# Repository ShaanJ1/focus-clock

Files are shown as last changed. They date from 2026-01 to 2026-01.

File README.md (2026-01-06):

# Focus Clock
A small battery powered pomorodo clock that can help you manage your time better. Includes pomorodo timer, custom timer support, screen time reminders, and more!

### Showcase
*Coming soon...*
### Bill of Materials (BOM)

| **Item Name** | **URL** | **Price** | **Quantity** |
|--- |---|---|---|
| SSD1306 OLED Display | [AliExpress](https://www.aliexpress.com/item/1005008640132638.html) | $5.58 | 1 |
| Rotary Encoder | [AliExpress](https://www.aliexpress.com/item/1005009532009840.html) | $14.23 | 1 |
| Vibration Motor | [DigiKey](https://www.digikey.ca/en/products/detail/adafruit-industries-llc/1201/5353637) | $2.82 | 1 |
| Speaker Driver | [DigiKey](https://www.digikey.ca/en/products/detail/dfrobot/DFR0299/6588463) | $8.53 | 1 | 
| Speaker | [DigiKey](https://www.digikey.ca/en/products/detail/soberton-inc/SP-1605-5/8600809) | $3.36 | 1 |
| 3.7V Battery (self provided, not included in total) | - | $0.00 | 1 |
| Adafruit Battery Charger (self provided, not included in total) | - | $0.00 | 1 |
| 1x2 Male Pin Connector | [DigiKey](https://www.digikey.ca/en/products/detail/w-rth-elektronik/61300211121/4846823) | $1.48 | 10 |
| 1x3 Male Pin Connector | [DigiKey](https://www.digikey.ca/en/products/detail/adam-tech/PH1-03-UA/9830289) | $0.15 | 1 |
| 1x4 Male Pin Connector | [DigiKey](https://www.digikey.ca/en/products/detail/adam-tech/PH1-04-UA/9829296) | $0.15 | 1 |
| 1x5 Male Pin Connector | [DigiKey](https://www.digikey.ca/en/products/detail/adam-tech/PH1-05-UA/9830343) | $0.15 | 1 |
| 2x3 Male Pin Connector | [DigiKey](https://www.digikey.ca/en/products/detail/adam-tech/PH2-06-UA/9830396) | $0.18 | 1 |
| PushButton | [DigiKey](https://www.digikey.ca/en/products/detail/same-sky-formerly-cui-devices-/TS02-66-43-BK-100-LCR-D/15634359)  | $0.45 | 3 |
| PCBA | [JLCPCB](https://jlcpcb.com/) | $35.78 | 1 |

**Total (CAD):** $72.86

**Total (USD):** $52.92

### Images
Schematic


PCB



Assembly


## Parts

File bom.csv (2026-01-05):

Bill of Materials
Item Name: | URL: | Price: | Quantity: | Use:
OLED Display | https://www.aliexpress.com/item/1005008640132638.html | $5.58 | 1 | Display
Rotary Encoder | https://www.aliexpress.com/item/1005003824684681.html | $5.50 | 1 | User Input
Vibration Motor | https://www.digikey.ca/en/products/detail/adafruit-industries-llc/1201/5353637 | $2.82 | 1 | Haptic Feedback
Speaker Driver | https://www.digikey.ca/en/products/detail/dfrobot/DFR0299/6588463 | $8.53 | 1 | Audio Driver
Speaker | https://www.digikey.ca/en/products/detail/soberton-inc/SP-1605-5/8600809 | $3.36 | 1 | Audio Output
3.7V Battery (Self Provided) |  | $0.00 | 1 | Power Source
Adafruit Battery Charger (Self Provided) |  | $0.00 | 1 | Battery Charging
1x2 Male Pin Connector | https://www.digikey.ca/en/products/detail/w-rth-elektronik/61300211121/4846823 | $1.48 | 10 | Board Connections
1x3 Male Pin Connector | https://www.digikey.ca/en/products/detail/adam-tech/PH1-03-UA/9830289 | $0.15 | 1 | Board Connections
1x4 Male Pin Connector | https://www.digikey.ca/en/products/detail/adam-tech/PH1-04-UA/9829296 | $0.15 | 1 | Board Connections
1x5 Male Pin Connector | https://www.digikey.ca/en/products/detail/adam-tech/PH1-05-UA/9830343 | $0.15 | 1 | Board Connections
2x3 Male Pin Connector | https://www.digikey.ca/en/products/detail/adam-tech/PH2-06-UA/9830396 | $0.18 | 1 | Board Connections
PushButton | https://www.digikey.ca/en/products/detail/same-sky-formerly-cui-devices-/TS02-66-43-BK-100-LCR-D/15634359 | $0.45 | 3 | User Input Buttons
PCBA | https://jlcpcb.com/ | $35.78 | 1 | Assembled PCB
3D Printing Shipping |  | $10.00 | 1 | 3D Print Shipping Costs
DigiKey Shipping + GST |  | $9.57 | 1 | DigiKey Shipping and tax
 | Total (CAD): | $73.70
 | Total (USD): | $53.57

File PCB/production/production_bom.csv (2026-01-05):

Designator | Footprint | Quantity | Value | LCSC Part #
C1, C2 | 0603 | 2 | 10uF
C10, C11, C12, C13, C14, C15, C17, C20, C24, C8, C9 | 0402 | 11 | 0.1uF
C16, C3 | 0402 | 2 | 1uF
C18, C19 | 0402 | 2 | 33pF
D2 | 0402 | 1 | ONBOARD_LED
D5 | D_DO-35_SOD27_P7.62mm_Horizontal | 1 | 1N4148
D6 | D_DO-41_SOD81_P10.16mm_Horizontal | 1 | 1N5817
J1 | PinHeader_1x02_P2.54mm_Vertical | 1 | Battery_Output
J10, J14, J9 | PinHeader_1x02_P2.54mm_Vertical | 3 | PushButton
J11 | PinHeader_1x02_P2.54mm_Vertical | 1 | LED_RED
J12 | PinHeader_1x02_P2.54mm_Vertical | 1 | LED_GREEN
J13 | PinHeader_1x02_P2.54mm_Vertical | 1 | LED_BLUE
J2 | PinHeader_1x04_P2.54mm_Vertical | 1 | SSD1306
J3 | PinHeader_1x02_P2.54mm_Vertical | 1 | Vibration_Motor
J4 | USB_C_Receptacle_HRO_TYPE-C-31-M-12 | 1 | USB_C_Receptacle_USB2.0_14P
J5 | PinHeader_2x03_P2.54mm_Vertical | 1 | DF Player Mini
J6 | PinHeader_1x03_P2.54mm_Vertical | 1 | Conn_01x03
J7 | PinHeader_1x02_P2.54mm_Vertical | 1 | Battery_Charger
J8 | PinHeader_1x05_P2.54mm_Vertical | 1 | RotaryEncoder
Q1 | SOT-23 | 1 | AO3401A
Q3 | SOT-23 | 1 | Q_NMOS_GSD
R1 | 0402 | 1 | 100
R10 | 0402 | 1 | 100K
R11, R12, R13, R2 | 0402 | 4 | 220
R21, R22 | 0402 | 2 | 4.7K
R3, R4 | 0402 | 2 | 27
R5, R7 | 0402 | 2 | 1K
R6 | 0402 | 1 | 10K
R8, R9 | 0402 | 2 | 5.1K
SW1 | SW_Push_SPST_NO_Alps_SKRK | 1 | SW_Push
U1 | SOT-23 | 1 | MCP1700x-330xxTT
U2 | SOIC-8_5.3x5.3mm_P1.27mm | 1 | W25Q128JVS
U3 | QFN-56-1EP_7x7mm_P0.4mm_EP3.2x3.2mm | 1 | RP2040
Y1 | Crystal_SMD_3225-4Pin_3.2x2.5mm | 1 | 12 MHz

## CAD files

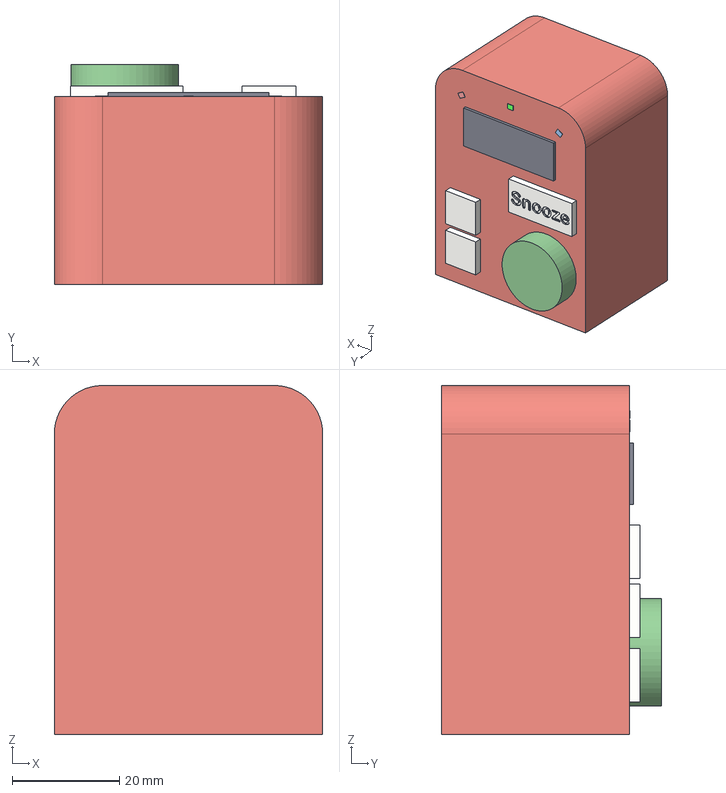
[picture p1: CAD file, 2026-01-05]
CAD/focus_clock.step
50.0 x 41.0 x 65.0 mm

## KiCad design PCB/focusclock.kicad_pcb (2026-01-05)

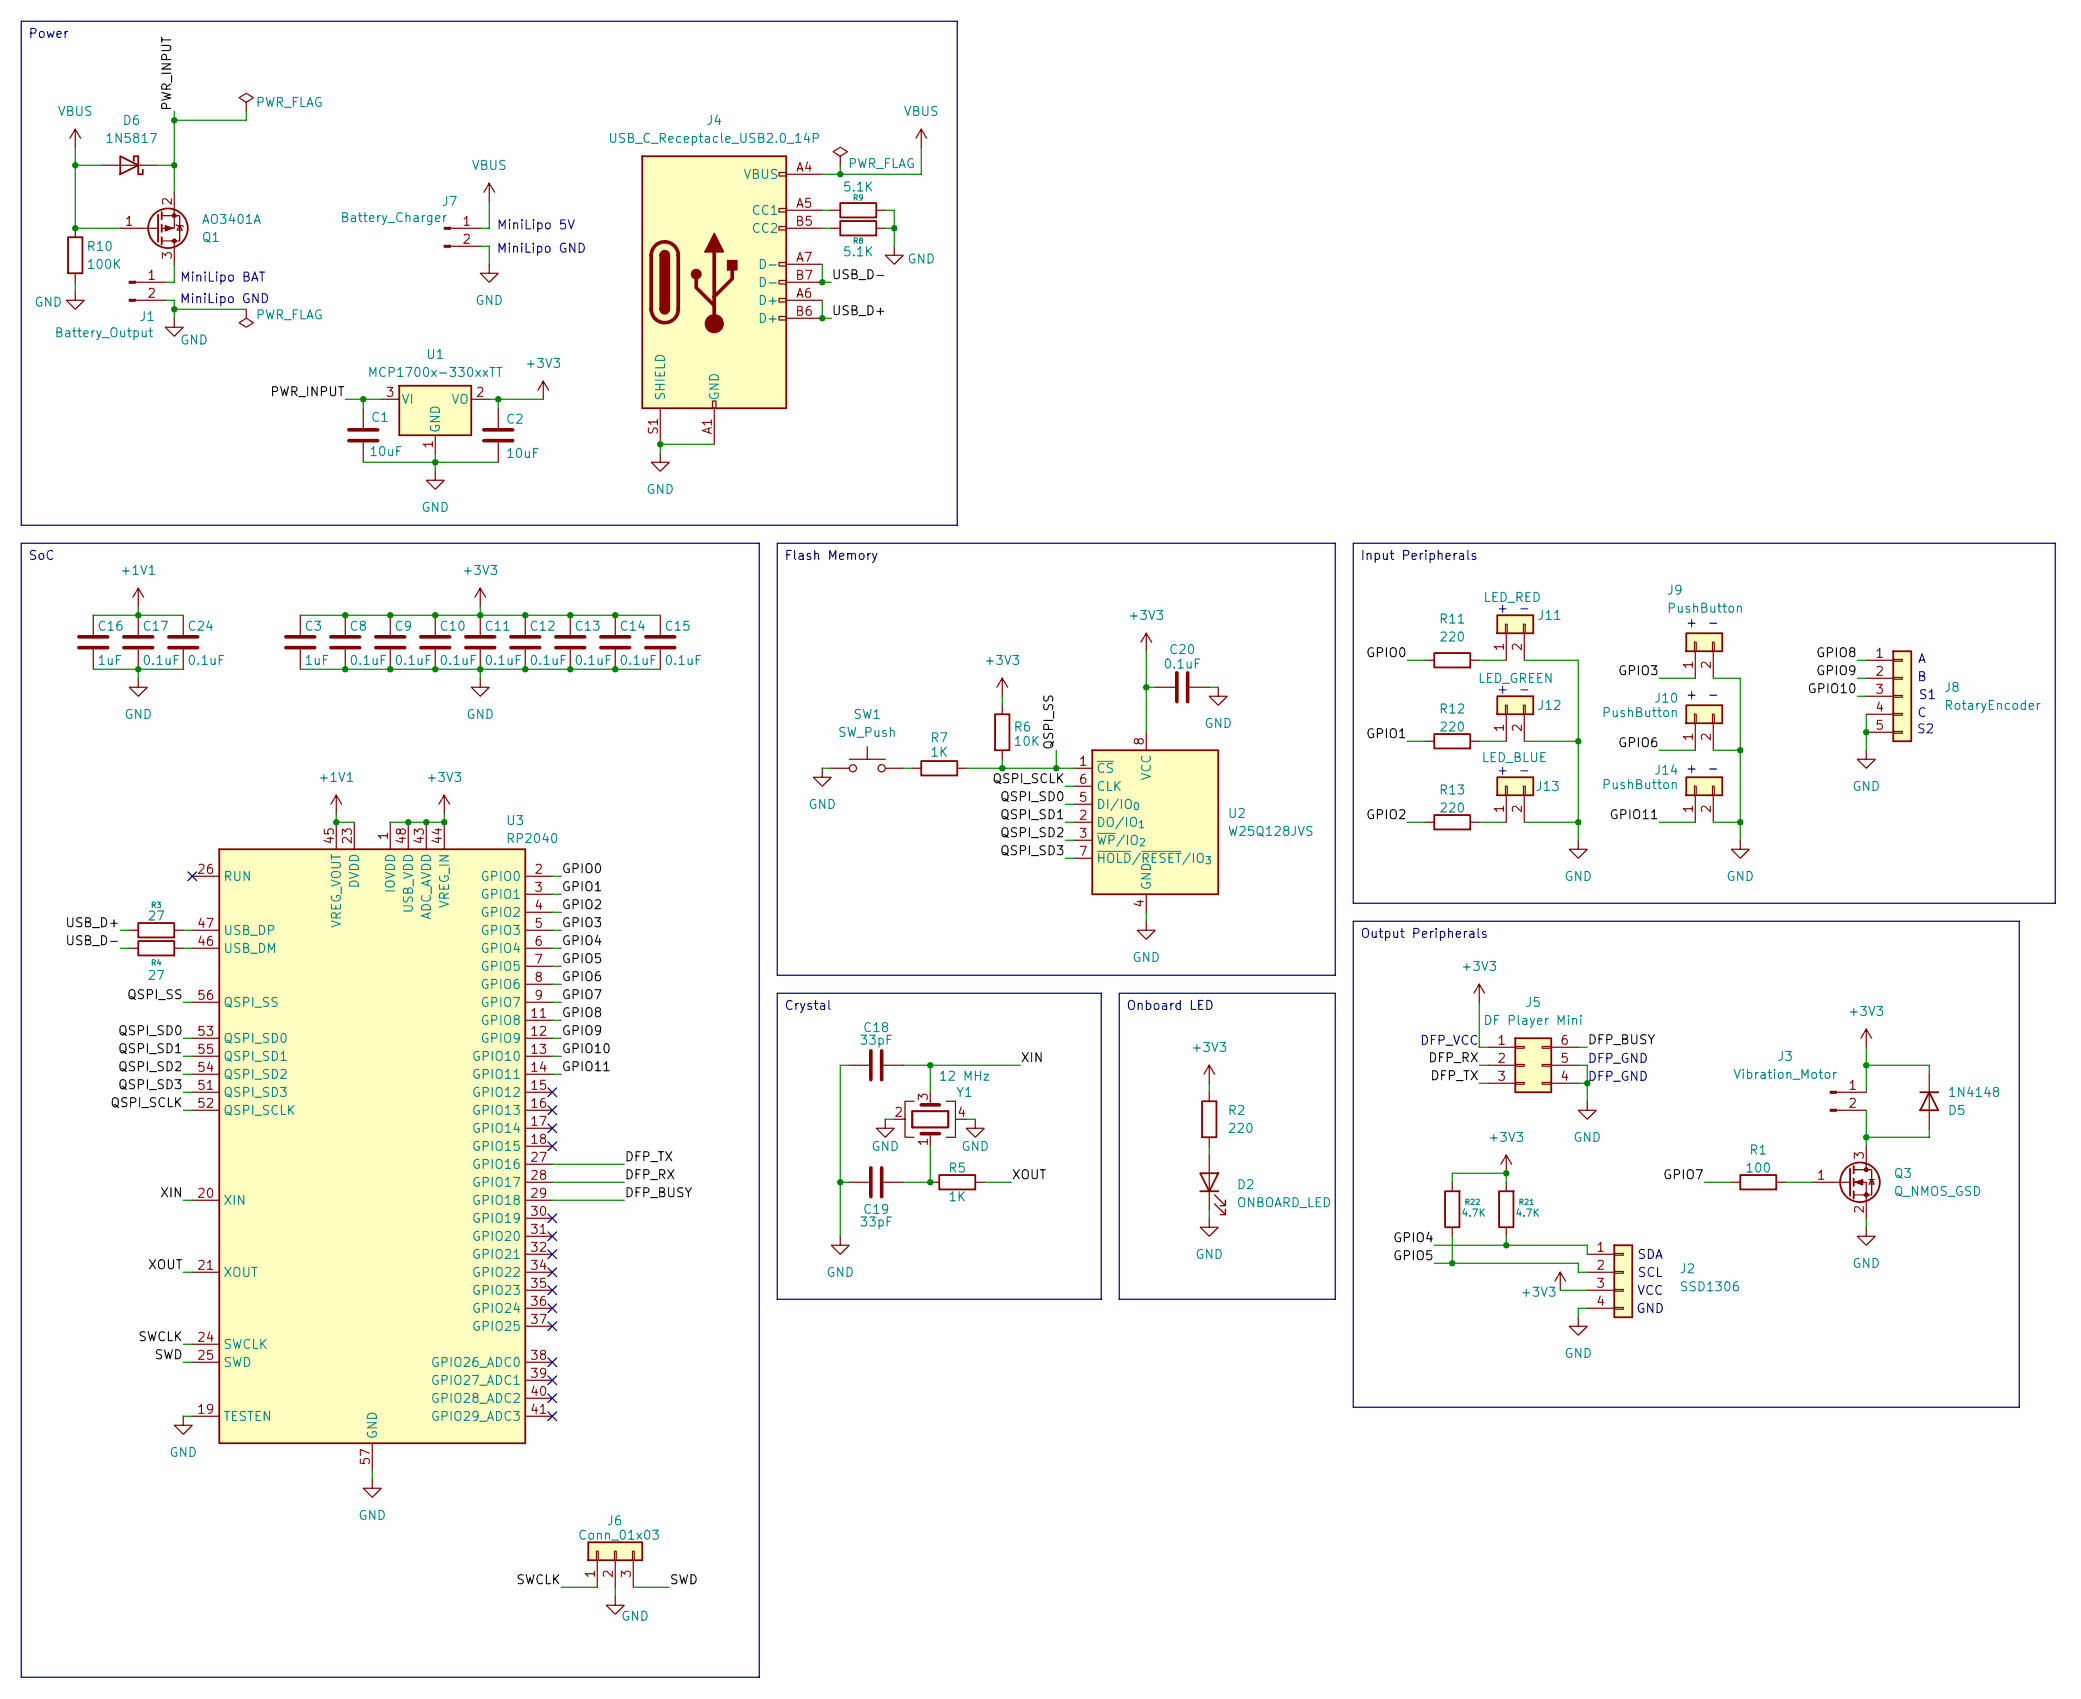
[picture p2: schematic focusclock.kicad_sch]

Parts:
C1, C2: 10uF; C_0603_1608Metric
C3, C16: 1uF; C_0402_1005Metric
C8, C9, C10, C11, C12, C13, C14, C15, C17, C20, C24: 0.1uF; C_0402_1005Metric
C18, C19: 33pF; C_0402_1005Metric
D2: ONBOARD_LED; LED_0402_1005Metric
D5: 1N4148; D_DO-35_SOD27_P7.62mm_Horizontal
D6: 1N5817; D_DO-41_SOD81_P10.16mm_Horizontal
J1: Battery_Output; PinHeader_1x02_P2.54mm_Vertical
J2: SSD1306; PinHeader_1x04_P2.54mm_Vertical
J3: Vibration_Motor; PinHeader_1x02_P2.54mm_Vertical
J4: USB_C_Receptacle_USB2.0_14P; USB_C_Receptacle_HRO_TYPE-C-31-M-12
J5: DF Player Mini; PinHeader_2x03_P2.54mm_Vertical
J6: Conn_01x03; PinHeader_1x03_P2.54mm_Vertical
J7: Battery_Charger; PinHeader_1x02_P2.54mm_Vertical
J8: RotaryEncoder; PinHeader_1x05_P2.54mm_Vertical
J9, J10, J14: PushButton; PinHeader_1x02_P2.54mm_Vertical
J11: LED_RED; PinHeader_1x02_P2.54mm_Vertical
J12: LED_GREEN; PinHeader_1x02_P2.54mm_Vertical
J13: LED_BLUE; PinHeader_1x02_P2.54mm_Vertical
Q1: AO3401A; SOT-23
Q3: Q_NMOS_GSD; SOT-23
R1: 100; R_0402_1005Metric
R2, R11, R12, R13: 220; R_0402_1005Metric
R3, R4: 27; R_0402_1005Metric
R5, R7: 1K; R_0402_1005Metric
R6: 10K; R_0402_1005Metric
R8, R9: 5.1K; R_0402_1005Metric
R10: 100K; R_0402_1005Metric
R21, R22: 4.7K; R_0402_1005Metric
SW1: SW_Push; SW_Push_SPST_NO_Alps_SKRK
U1: MCP1700x-330xxTT; SOT-23
U2: W25Q128JVS; SOIC-8_5.3x5.3mm_P1.27mm
U3: RP2040; QFN-56-1EP_7x7mm_P0.4mm_EP3.2x3.2mm
Y1: 12 MHz; Crystal_SMD_3225-4Pin_3.2x2.5mm

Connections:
+1V1: C16.1, C17.1, C24.1, U3.23 (DVDD), U3.45 (VREG_VOUT), U3.50 (DVDD)
+3V3: C2.1, C3.1, C8.1, C9.1, C10.1, C11.1, C12.1, C13.1, C14.1, C15.1, C20.1, D5.1 (K), J2.3, J3.1, J5.1, R2.1, R6.1, R21.2, R22.2, U1.2 (VO), U2.8 (VCC), U3.1 (IOVDD), U3.10 (IOVDD), U3.22 (IOVDD), U3.33 (IOVDD), U3.42 (IOVDD), U3.43 (ADC_AVDD), U3.44 (VREG_IN), U3.48 (USB_VDD), U3.49 (IOVDD)
/DFP_BUSY: J5.6, U3.29 (GPIO18)
/DFP_RX: J5.2, U3.28 (GPIO17)
/DFP_TX: J5.3, U3.27 (GPIO16)
/GPIO0: R11.1, U3.2 (GPIO0)
/GPIO1: R12.1, U3.3 (GPIO1)
/GPIO2: R13.1, U3.4 (GPIO2)
/GPIO3: J9.1, U3.5 (GPIO3)
/GPIO4: J2.1, R21.1, U3.6 (GPIO4)
/GPIO5: J2.2, R22.1, U3.7 (GPIO5)
/GPIO6: J10.1, U3.8 (GPIO6)
/GPIO7: R1.1, U3.9 (GPIO7)
/GPIO8: J8.1, U3.11 (GPIO8)
/GPIO9: J8.2, U3.12 (GPIO9)
/GPIO10: J8.3, U3.13 (GPIO10)
/GPIO11: J14.1, U3.14 (GPIO11)
/PWR_INPUT: C1.1, D6.1 (K), Q1.2 (S), U1.3 (VI)
/QSPI_SCLK: U2.6 (CLK), U3.52 (QSPI_SCLK)
/QSPI_SD0: U2.5 (DI/IO_{0}), U3.53 (QSPI_SD0)
/QSPI_SD1: U2.2 (DO/IO_{1}), U3.55 (QSPI_SD1)
/QSPI_SD2: U2.3 (~WP/IO_{2}), U3.54 (QSPI_SD2)
/QSPI_SD3: U2.7 (~HOLD/~RESET/IO_{3}), U3.51 (QSPI_SD3)
/QSPI_SS: R6.2, R7.2, U2.1 (~CS), U3.56 (QSPI_SS)
/SWCLK: J6.1, U3.24 (SWCLK)
/SWD: J6.3, U3.25 (SWD)
/USB_D+: J4.A6 (D+), J4.B6 (D+), R3.1
/USB_D-: J4.A7 (D-), J4.B7 (D-), R4.1
/XIN: C18.2, U3.20 (XIN), Y1.3
/XOUT: R5.2, U3.21 (XOUT)
GND: C1.2, C2.2, C3.2, C8.2, C9.2, C10.2, C11.2, C12.2, C13.2, C14.2, C15.2, C16.2, C17.2, C18.1, C19.1, C20.2, C24.2, D2.1 (K), J1.2, J2.4, J4.A1 (GND), J4.A12 (GND), J4.B1 (GND), J4.B12 (GND), J4.S1 (SHIELD), J5.4, J5.5, J6.2, J7.2, J8.4, J8.5, J9.2, J10.2, J11.2, J12.2, J13.2, J14.2, Q3.2 (S), R8.2, R9.2, R10.2, SW1.1, U1.1 (GND), U2.4 (GND), U3.19 (TESTEN), U3.57 (GND), Y1.2, Y1.4
unnamed: C19.2, R5.1, Y1.1
unnamed: D2.2 (A), R2.2
unnamed: D5.2 (A), J3.2, Q3.3 (D)
unnamed: J1.1, Q1.3 (D)
unnamed: J4.A5 (CC1), R8.1
unnamed: J4.B5 (CC2), R9.1
unnamed: J11.1, R11.2
unnamed: J12.1, R12.2
unnamed: J13.1, R13.2
unnamed: Q3.1 (G), R1.2
unnamed: R7.1, SW1.2
unnamed: R4.2, U3.46 (USB_DM)
unnamed: R3.2, U3.47 (USB_DP)
VBUS: D6.2 (A), J4.A4 (VBUS), J4.A9 (VBUS), J4.B4 (VBUS), J4.B9 (VBUS), J7.1, Q1.1 (G), R10.1

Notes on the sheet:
DFP_GND
MiniLipo GND
GND
DFP_VCC
SCL
VCC
MiniLipo 5V
MiniLipo BAT
SDA
Input Peripherals
Crystal
SoC
Power
Output Peripherals
Onboard LED
Flash Memory

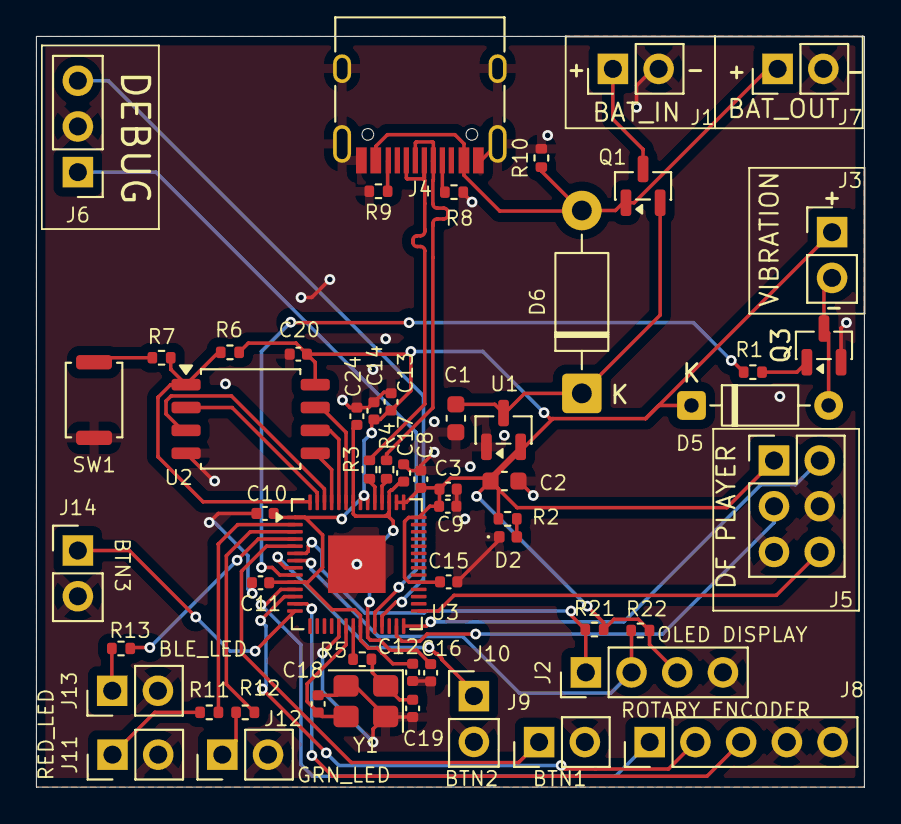
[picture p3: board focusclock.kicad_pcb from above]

Board: 2 copper layers, 46.0 x 41.7 mm, 56 parts (0 on the bottom side), 45 nets.
